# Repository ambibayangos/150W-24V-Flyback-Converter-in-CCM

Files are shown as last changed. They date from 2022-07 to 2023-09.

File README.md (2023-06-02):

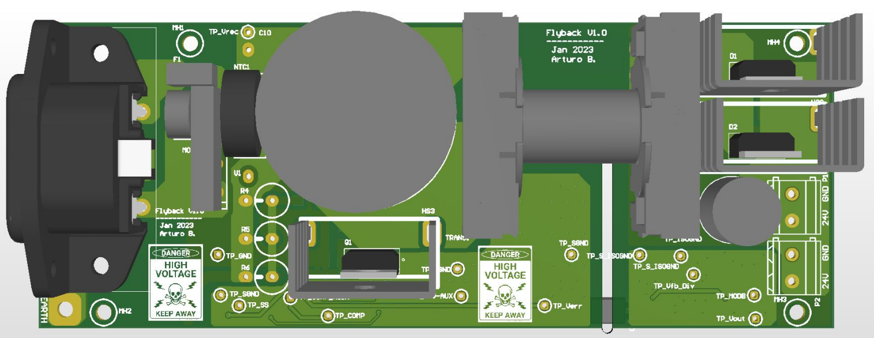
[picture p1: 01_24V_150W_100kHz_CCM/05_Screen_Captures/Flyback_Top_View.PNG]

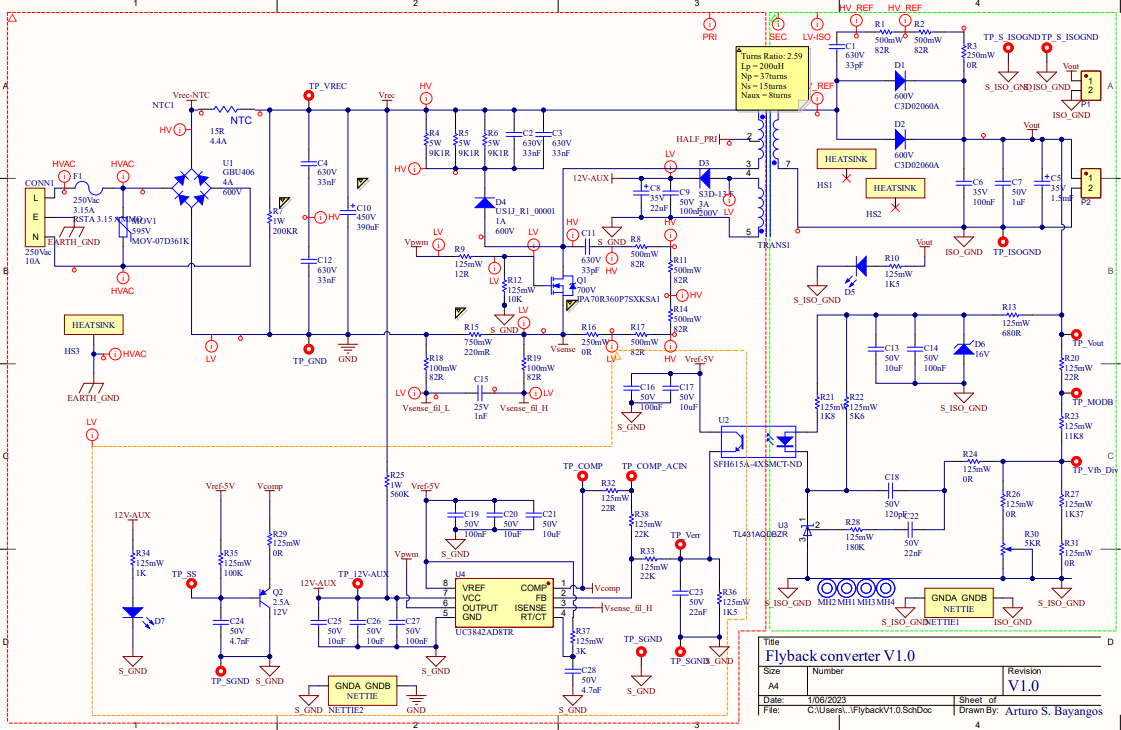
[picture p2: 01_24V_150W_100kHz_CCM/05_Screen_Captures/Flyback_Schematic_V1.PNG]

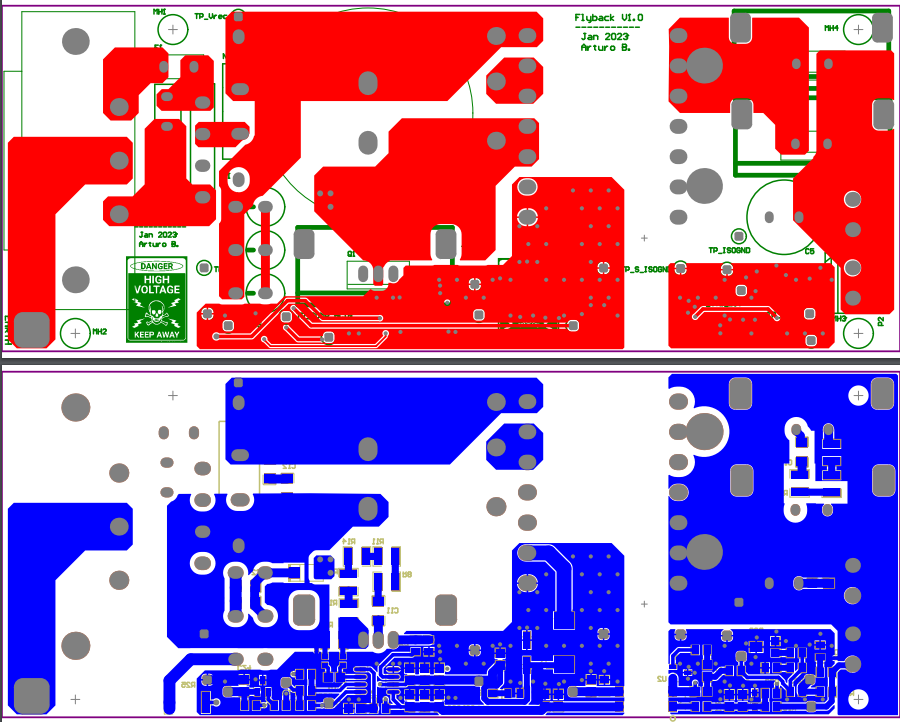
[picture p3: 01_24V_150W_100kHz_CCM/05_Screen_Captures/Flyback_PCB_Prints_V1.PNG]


# About
In this project I am designing and building a 60W,20V, dual channel digital power supply. The user will be able to set  the power supply voltage and max current using tactile buttons and an LCD display will show them their inputs as well as the PSU status.

A 150W flyback converter will convert the AC voltage from the grid to a safe DC voltage. Then, two synchronous buck converter will condition the output of the flyback converter at the user’s command which is done in the background with a microcontroller.
# Motivation
I wanted to learn how to design the feedback loop for an isolated power converter which is commonly found on flyback converter. Also, I wanted to learn how to control an LCD using a microcontroller. Finally, even though I have programmed in C before, I have always done it using ATMEL microcontroller. This time I wanted to play around with STM32 or ESP32 microcontrollers.
# Progress and What's coming
* I have designed the first protoype for the flyback converter and have the PCB file ready to be manufacture. However, I am currently too poor to buy the components to assemble it.

* I have started to design the synchronous buck converter. I have gathered enough information to pick the components for the power section. Next I need to think about how I am going to control it, and how I will implement the protection schemes.

* I need to write the code to handle the user inputs and translate them for the buck converter,  and I also need to write the logic to control the LCD display.

* Finally, I need to design an enclosure for the digital power supply.

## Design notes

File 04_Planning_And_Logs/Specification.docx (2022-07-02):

# Specification for the 150W, 12V Flyback converter in DCM

Below are the of the basic specification for this flyback converter project.

- Maximum output power: 150W
- Regulated voltage: 12V
- Switching frequency: 100kHz
- Flyback operates in DCM
- Input voltage: 230VAC
- Assumed input voltage variation: +-20%
- Assumed overall efficiency: 80%

Notes:

A quick search online indicates that in Australia, the nominal mains voltage is 230VAC (same as New Zealand) with +10% to -6% variation in accordance with the system standard AS60038.

The specification input voltage variation of 20% might be too extreme, however, since the coupled inductor could saturate at higher duty cycles which occurs at lower input voltages, the input voltage variation is decided to be exaggerated to ensure reliability for now.

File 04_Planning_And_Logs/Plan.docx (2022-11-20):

- Need to test if grounding the heatsink if the measured EMI would be reduced.
- Need to measure the open-loop response of the converter using spectrum analyser.
- Test if the simulated temperature rise in the core is same as simulation. Also Need to test if the saturation of the simulated core has same saturation current as the real core. Can also compare with analytical solution from reference books.

Verify the magnetic design with MAXWELL.

This means verify the saturation current and also verify the temperature rise is good using ICEPAK.

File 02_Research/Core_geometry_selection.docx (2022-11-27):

Pot cores

Pot cores are good for low profile applications. They naturally shield the “stray” H-field because of their enclosed geometry. However, they are not cheap.

E-cores

E cores are good for high power applications because the winding around them can be cooled more effectively due to their open construction geometry. They are apparently, easier to wind and have a lot of hardware support such as many options of bobbin and landing patterns.

Overall, this core seems to the most standardised core shape.

ETD cores or cores with round centre post (also applies for EC and EER cores)

These cores have shorter path length, which means the overall copper loss in reduced for the same number of turns. Like E-cores, they are good for high power applications since their winding can be cooled due to their wider opening construction.

Links

https://www.electronicdesign.com/technologies/passive-components/article/21192374/one-powerful-decade-keep-core-geometry-in-mind-when-designing-transformers

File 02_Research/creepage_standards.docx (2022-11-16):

Creepage distance is determined given the working RMS voltage, the pollution degree, and the material group.

The material group is defined by the CTI of the surface. The CTI can be thought of as a resistance that prevents current to flow between conductors. Thus, higher CTI means better protection against failure due to creepage.

I wonder how creepage applies to tracts inside the PCB.

It seems that pollution degree 1 can be assumed when there is no dust or moisture that can come on the PCB. Conformal coating solves this issue.

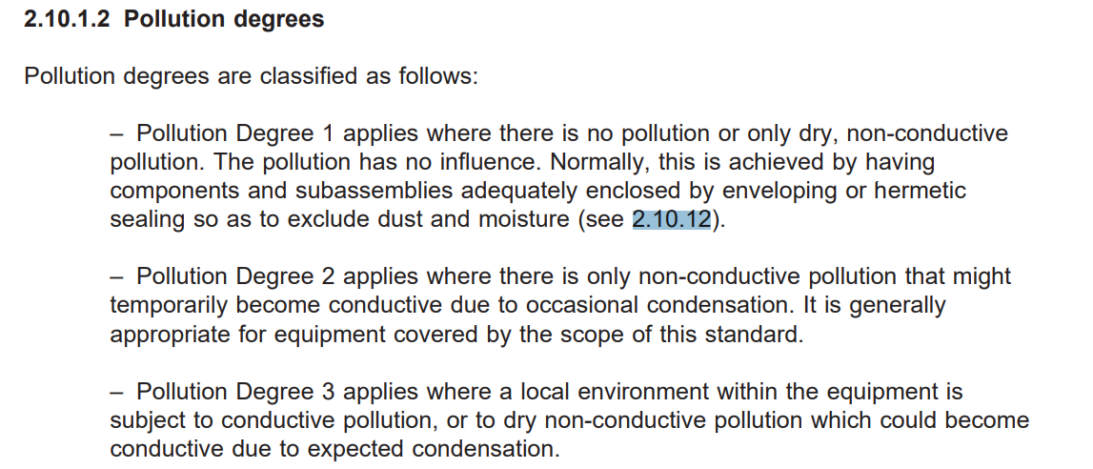
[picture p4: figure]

https://composter.com.ua/documents/IEC60950-1.pdf

https://www.techspray.com/the-essential-guide-to-conformal-coating

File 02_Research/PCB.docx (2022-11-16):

I will use critical thinking to arrive at solutions based on reasons.

A tool I can use to facilitate critical thinking is asking insightful questions. Kinda like the socratic method. In the Socratic method, one probes another’s line of thoughts by asking them questions.

But solving any problem requires initial thoughts which can be refined if needed. If I just use common sense, I should be able to arrive to solution without conducting much research but still produce a reliable product. For example, if you know the board may caught or fire then use fireproof components. Basically, the idea is to draw inspirations from experience. But of course, some things are not as obvious as you might think and require research. Things like EMI problems.

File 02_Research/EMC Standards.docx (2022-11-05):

Standards

To sell a product in a market, such product typically need to carry the certification mark required in that region. These certification mark , e.g. CE & UL, are attained by adhering the standards proposed by some testing agencies e.g. UL (underwritters Laboratories), then the product needs to be tested by the agencies in able to ensure that the product does indeed adhered to the standards they proposed.

In most countries the safety and EMC compliance mark is usually combined. But for US, the safety mark is called UL and the EMC mark if FCC.

For a tpical engineer trying to comply with EMI see “EN 550022” (Meant for IT equipment). Which is also known as CISPR22. And the American counter part is FCC part 15.

The changing magnetic and electromagnetic fields in SMPs can generate electro-magnetic fields (near field) but at some distance away they become electro-magnetic waves which can propagate into the space. This propagated wave can be picked up by other devices thus generating unwated current or voltages which can cause that particular device to malfunction. Also the radiated waves can be picked up again by the conveter it self thus contributing to it own noise.

In general as frequency increases, the electro-magnetic fields gets more intense. Thus increasing the EMI. This is because as frequency increases, the smaller trace length can be more conductive or can radiate the high frequency contents/ energy in the harmonics of the SMPs.

For EMI radiated test, the frequency can start from 30MHz-1Ghz at distances of 3m (for FCC) and 10m for (CISPR). At these distances, the EM waves will be far field.

EMC class

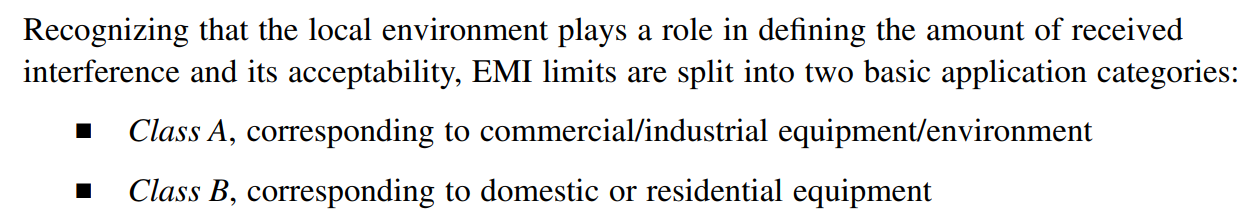
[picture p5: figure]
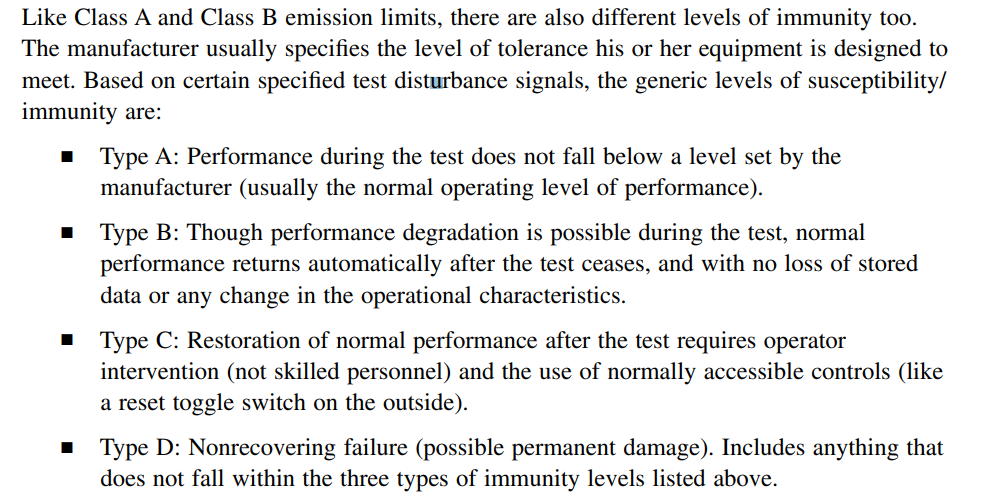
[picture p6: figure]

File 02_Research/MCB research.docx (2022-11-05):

What is MCB (Miniature Circuit Breaker)

MCBs are the circuit breakers typically found in most modern households. They are basically re-settable fuse. They can trip with two modes. First mode is slow and the trip action is due to temperature rise due to prolonged high current. The second mode is much faster which is meant to protect under short circuit conditions. The second mode has a trip reaction time of 100ms, which means that after dectecting a short, the circuit breaker can break the current within 100ms.

MCBs look like this:

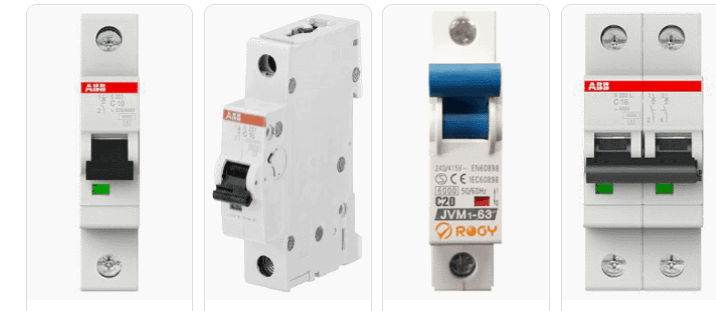
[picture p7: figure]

Types of MCB

MCBs have a rated trip current. And it addition to that, MCB also have the so called trip curves. These trip curves vary from C,B,D,A and even Z. Trip curves shows at what current the MCB will trip practically instantly. For example. For an MCB with a trip “B” trip curve, The MCB will instantly trip at 3-5 times the rated full load current, while an MCB with a “C” trip curve will instantly trip at 5-10 times of the rated full load current. Below is the trip curves (https://www.electricalclassroom.com/b-c-d-k-and-z-mcb-trip-curves/).

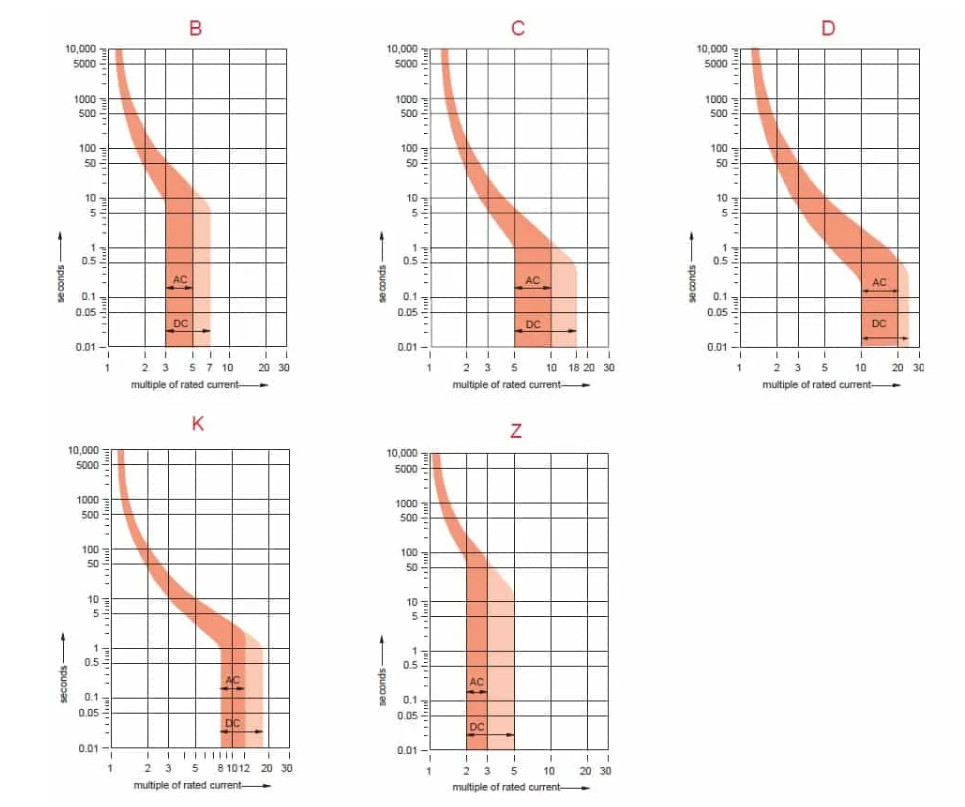
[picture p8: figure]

What type of MCB is used for home?

Seems like either MCBs that have B or C trip curves are used for home applications. See snapshot below(https://www.consumerunitworld.co.uk/what-is-an-mcb-and-how-does-it-work-328-c.asp).

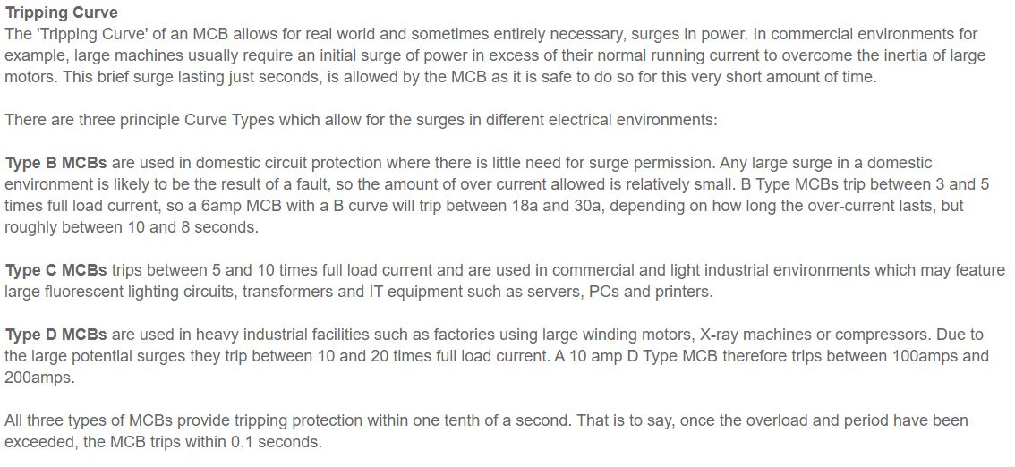
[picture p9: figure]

Further

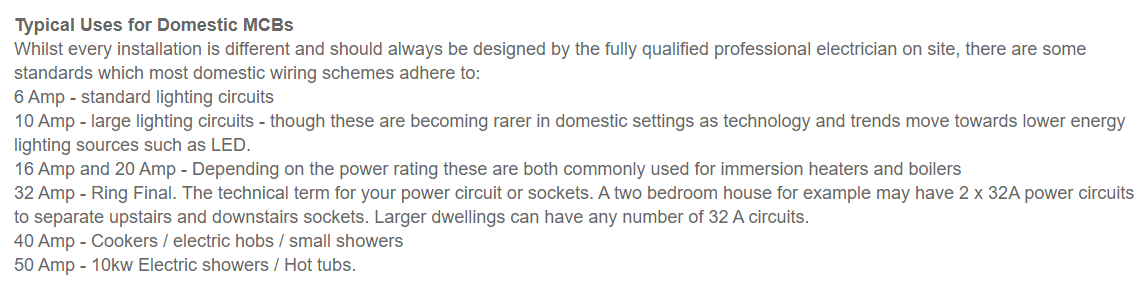
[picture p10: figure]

Conclusion

MCBs used in power sockets are likely to be 16-32A MCBs that have either “B” (3-5 x full current) or “C” (5-10 x full current).

I had a look at the MCBs of a house (@ snapperrock) it seems that the lights uses C10A , while power uses C16A or C20A. I am assuming power means the power sockets.

Ofcourse, the power sockets have other circuits connected to it that why the trip current is probably higher. But there is no way of knowing what circuits are connected to what loop.

Links

https://www.electricalclassroom.com/b-c-d-k-and-z-mcb-trip-curves/

https://www.consumerunitworld.co.uk/what-is-an-mcb-and-how-does-it-work-328-c.asp

https://uk.rs-online.com/web/generalDisplay.html?id=ideas-and-advice/mcb-guide

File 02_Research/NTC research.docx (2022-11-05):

Dissipation factor and what it means

Dissipation factor gives the rate of heat generated per second (i.e Ploss) for a given temperature rise above the ambient temperature. Therefore, it has a unit of W/K.

Power limitation of the device

It seems that the power limitation of the device, Pmax, gives the amount of power dissipation before the NTC goes into thermal runaway. Thus, I think Pmax is the power where the amount of energy generated within the NTC is equal to the amount of energy the NTC can remove from its body

Ctest

In for NTC used for inrush current limiting, the inrush current can be associated with a pulse of energy during the impulse. This energy needs to know in able to select an appropriate NTC size. Manufacturers typically, associate this energy with a capacitor discharge for a given voltage thus giving a capacitance for a given voltage and energy.

General steps to pick

1.)Pick the size – Size can be determined by the Ctest. Basically, if the pulse energy is known , then a corresponding Ctest can be matched for a given line voltage.

2.) Choose the R25 to limit the inrush current.

3.) Make sure the maximum steady state current if higher enough.

Links

https://www.newark.com/wcsstore/ExtendedSitesCatalogAssetStore/cms/asset/images/americas/common/storefront/epcos/inrushCurrentLimiters.pdf

https://www.tdk-electronics.tdk.com/download/2982800/f5be4fca9d1f66204de9cf37891e5265/ntc-thermistors-icl-an.pdf

https://www.tdk-electronics.tdk.com/download/531338/d80caa7d75198765c2534bc19da9b73d/pdf-general-technical-information.pdf

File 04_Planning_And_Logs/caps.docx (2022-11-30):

D = 0.18 , Vout = 16ishV

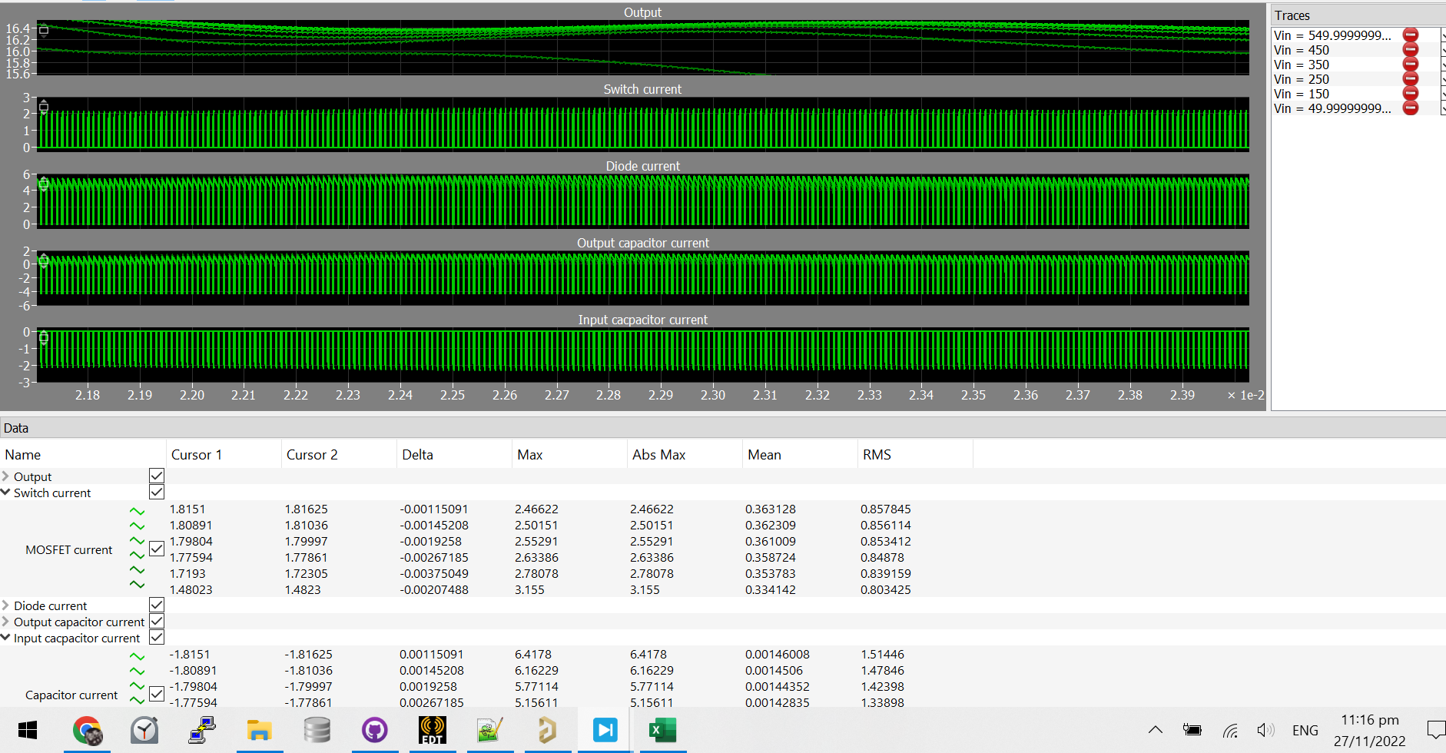
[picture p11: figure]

D = 0.25 , Vo = 25ish

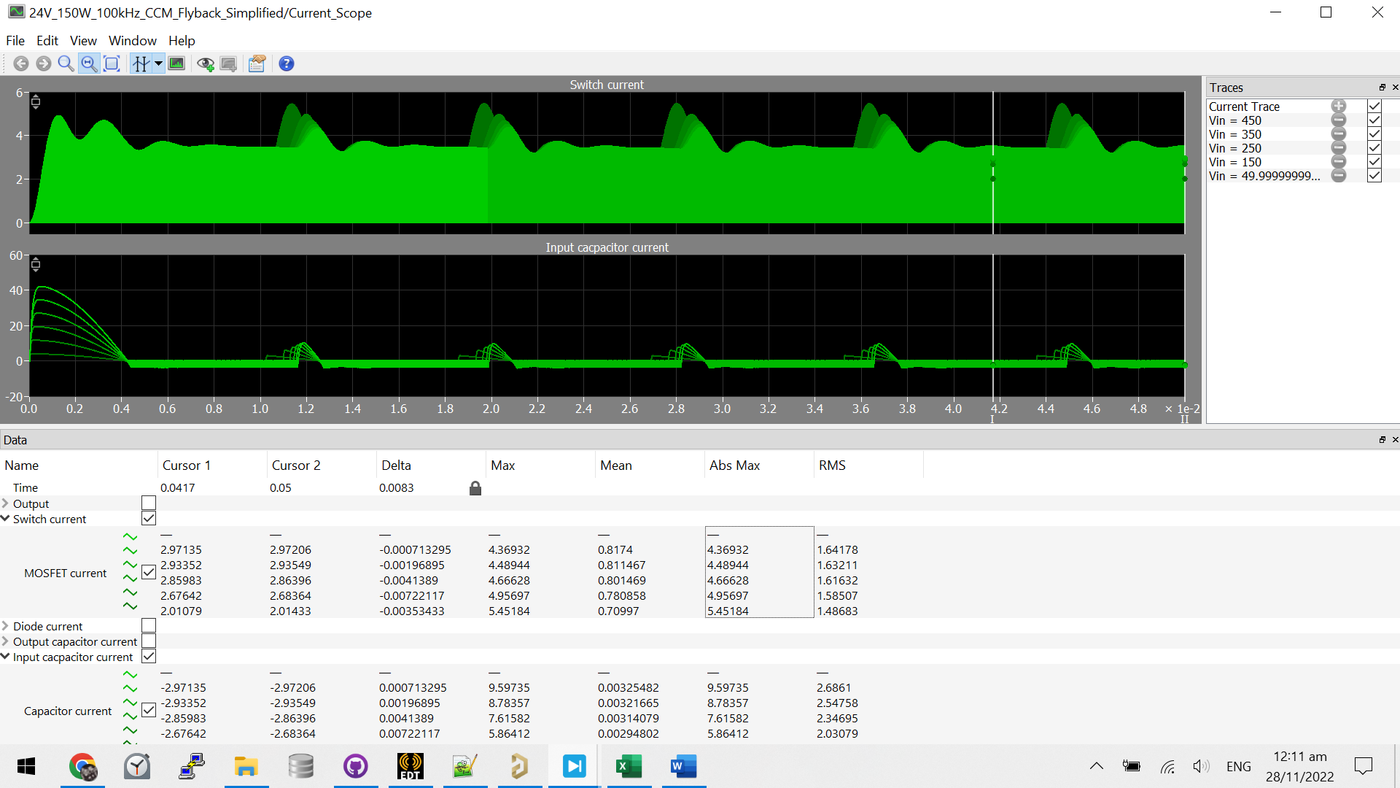
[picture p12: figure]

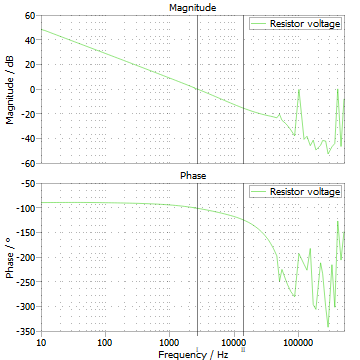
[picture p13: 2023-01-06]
01_24V_150W_100kHz_CCM/05_Screen_Captures/CCM_24V_150W_Open_Loop_Lp200uH_Compensated.png

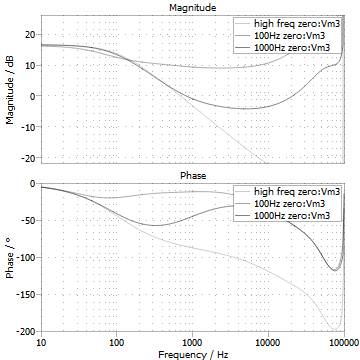
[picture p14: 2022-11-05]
01_24V_150W_100kHz_CCM/05_Screen_Captures/CCM_24V_150W_Open_Loop_Response.png

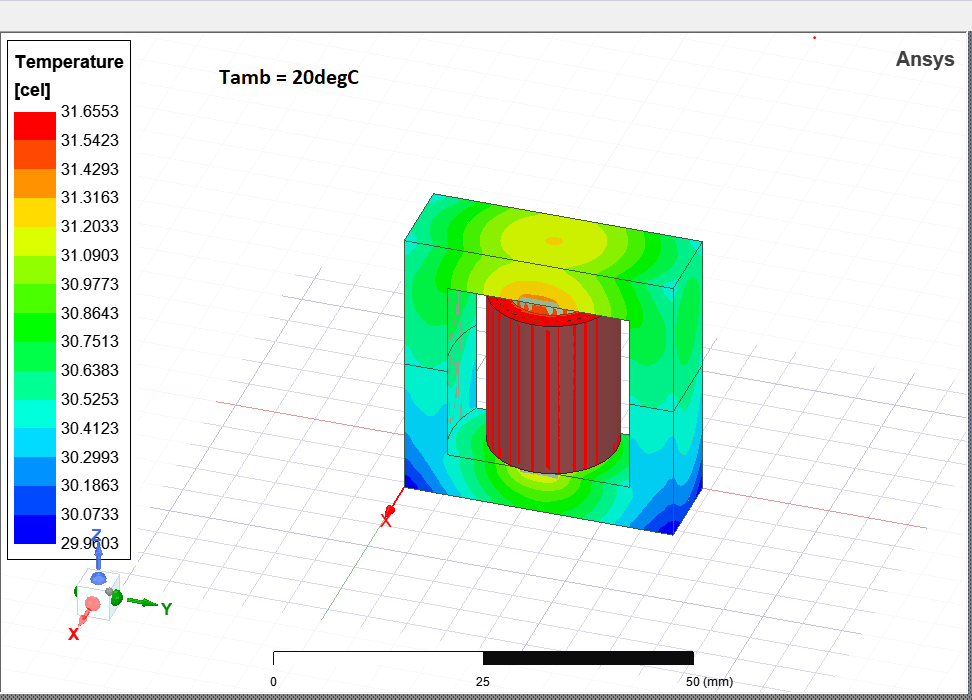
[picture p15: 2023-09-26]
01_24V_150W_100kHz_CCM/05_Screen_Captures/ETD34_1mm_20degCAmb.png

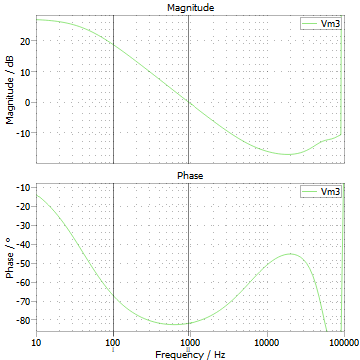
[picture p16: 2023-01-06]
01_24V_150W_100kHz_CCM/05_Screen_Captures/CCM_24V_150W_Open_Loop_Lp200uH.png

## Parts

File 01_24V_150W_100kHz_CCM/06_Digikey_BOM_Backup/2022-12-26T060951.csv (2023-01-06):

Index | Quantity | Part Number | Manufacturer Part Number | Description | Customer Reference | Available | Backorder | Unit Price | Extended Price NZD
1 | 2 | 565-4474-ND | ESMR401VSN391MA25S | CAP ALUM 390UF 20% 400V SNAP | Cin - 2.05A @ 120Hz , 400V | 2 | 0 | 12.47000 | 24.94
2 | 4 | 495-3058-ND | B57238S0150M000 | ICL 15 OHM 20% 4.4A 16MM | NTC 16MM 700UF , 15OHM | 4 | 0 | 2.32000 | 9.28
3 | 1 | 3M10226-ND | 3/4-5-1205 | TAPE FILM AMBER 3/4"X 5YDS | INSULATION TAPE | 1 | 0 | 41.21000 | 41.21
4 | 4 | IPA70R360P7SXKSA1-ND | IPA70R360P7SXKSA1 | MOSFET N-CH 700V 12.5A TO220 | MAIN MOSFET | 4 | 0 | 3.40000 | 13.60
5 | 2 | 732-9228-1-ND | 860040578017 | CAP ALUM 1500UF 20% 35V RADIAL | Cout - 35V , 3A @100kHz, 1.5mF | 2 | 0 | 4.25000 | 8.50
6 | 6 | A142823CT-ND | ROX5SSJ9K1 | RES 9.1K OHM 5% 5W AXIAL | RCD resistor - 9.1k,5W,750V (need 3 in parallel) | 6 | 0 | 1.13000 | 6.78
7 | 4 | 31-FUS1JE-7CT-ND | FUS1JE-7 | DIODE GEN PURP 600V 1A F1A | RCD diode - 600V , 1.7V , Trr = 75ns | 4 | 0 | 0.64000 | 2.56
8 | 2 | 1801-GBU406-ND | GBU406 | BRIDGE RECT 1PHASE 800V 4A GBU | Bridge rectifier | 2 | 0 | 2.22000 | 4.44
9 | 4 | C3D02060A-ND | C3D02060A | DIODE SIL CARB 600V 5A TO220-2 | Output diode - 600V , Vf = 1.7V , SiC , T0-220 | 4 | 0 | 2.82000 | 11.28
10 | 4 | AE10898-ND | V5630-T | HEATSINK ALUM ANOD | MOSFET and DIODE HEATSINK - 15.00°C/W | 4 | 0 | 0.82000 | 3.28
11 | 2 | 1189-3666-ND | 35ZLQ1500MEFC12.5X30 | CAP ALUM 1500UF 20% 35V RADIAL | Output cap , 1.5mF , 35V , Irms = 3.68A @ 100khz | 2 | 0 | 2.90000 | 5.80
12 | 6 | 507-1870-1-ND | RSTA 3.15 AMMO | FUSE BRD MNT 3.15A 250VAC/63VDC | Input fuse | 6 | 0 | 0.64600 | 3.88
13 | 4 | MOV-07D361K-ND | MOV-07D361K | VARISTOR 360V 1.2KA DISC 7MM | MOV - 595V @ 10A for 20-30us | 4 | 0 | 0.61000 | 2.44
14 | 4 | VR68J200KCT-ND | VR68000002003JAC00 | RES 200K OHM 1W 5% AXIAL | Bleed resistor- 200kR , 1W , 10kV | 4 | 0 | 1.38000 | 5.52
15 | 3 | 495-5464-ND | B66362B1014T001 | BOBBIN COIL FORMER ETD 34X17X11 | ETD34 - Bobbin Horizontal | 3 | 0 | 4.11000 | 12.33
16 | 8 | 495-5463-ND | B66362A2000X000 | YOKE ETD 34 X 17 X 11 | ETD34 Yoke | 8 | 0 | 0.97000 | 7.76
17 | 2 | 495-5462-ND | B66361G0000X187 | FERRITE CORE ETD N87 1PC | ETD34 - Not Gapped | 2 | 0 | 2.77000 | 5.54
18 | 2 | 495-5457-ND | B66361G1000X187 | FERRITE CORE ETD N87 1PC | ETD34 - 1mm gap | 2 | 0 | 3.77000 | 7.54
19 | 4 | SFH615A-4XSMCT-ND | SFH615A-4XSMT/R | OPTOISOLATOR 5.3KV TRANS 4SMD | optocoupler SMD | 4 | 0 | 0.91000 | 3.64

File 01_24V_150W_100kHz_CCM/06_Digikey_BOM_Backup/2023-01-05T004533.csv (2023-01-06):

Index | Quantity | Part Number | Manufacturer Part Number | Description | Customer Reference | Available | Backorder | Unit Price | Extended Price NZD
1 | 2 | 565-4474-ND | ESMR401VSN391MA25S | CAP ALUM 390UF 20% 400V SNAP | Cin - 2.05A @ 120Hz , 400V | 2 | 0 | 11.81000 | 23.62
2 | 4 | 495-3058-ND | B57238S0150M000 | ICL 15 OHM 20% 4.4A 16MM | NTC 16MM 700UF , 15OHM | 4 | 0 | 2.20000 | 8.80
3 | 1 | 3M10226-ND | 3/4-5-1205 | TAPE FILM AMBER 3/4"X 5YDS | INSULATION TAPE | 1 | 0 | 43.32000 | 43.32
4 | 4 | IPA70R360P7SXKSA1-ND | IPA70R360P7SXKSA1 | MOSFET N-CH 700V 12.5A TO220 | MAIN MOSFET | 4 | 0 | 3.07000 | 12.28
5 | 2 | 732-9228-1-ND | 860040578017 | CAP ALUM 1500UF 20% 35V RADIAL | Cout - 35V , 3A @100kHz, 1.5mF | 2 | 0 | 4.02000 | 8.04
6 | 6 | A142823CT-ND | ROX5SSJ9K1 | RES 9.1K OHM 5% 5W AXIAL | RCD resistor - 9.1k,5W,750V (need 3 in parallel) | 6 | 0 | 1.13000 | 6.78
7 | 4 | 31-FUS1JE-7CT-ND | FUS1JE-7 | DIODE GEN PURP 600V 1A F1A | RCD diode - 600V , 1.7V , Trr = 75ns | 4 | 0 | 0.63000 | 2.52
8 | 2 | 1801-GBU406-ND | GBU406 | BRIDGE RECT 1PHASE 800V 4A GBU | Bridge rectifier | 2 | 0 | 2.22000 | 4.44
9 | 4 | C3D02060A-ND | C3D02060A | DIODE SIL CARB 600V 5A TO220-2 | Output diode - 600V , Vf = 1.7V , SiC , T0-220 | 4 | 0 | 2.82000 | 11.28
10 | 4 | AE10898-ND | V5630-T | HEATSINK ALUM ANOD | MOSFET and DIODE HEATSINK - 15.00°C/W | 4 | 0 | 0.82000 | 3.28
11 | 2 | 1189-3666-ND | 35ZLQ1500MEFC12.5X30 | CAP ALUM 1500UF 20% 35V RADIAL | Output cap , 1.5mF , 35V , Irms = 3.68A @ 100khz | 2 | 0 | 2.90000 | 5.80
12 | 6 | 507-1870-1-ND | RSTA 3.15 AMMO | FUSE BRD MNT 3.15A 250VAC/63VDC | Input fuse | 6 | 0 | 0.64600 | 3.88
13 | 4 | MOV-07D361K-ND | MOV-07D361K | VARISTOR 360V 1.2KA DISC 7MM | MOV - 595V @ 10A for 20-30us | 4 | 0 | 0.61000 | 2.44
14 | 4 | VR68J200KCT-ND | VR68000002003JAC00 | RES 200K OHM 1W 5% AXIAL | Bleed resistor- 200kR , 1W , 10kV | 4 | 0 | 1.38000 | 5.52
15 | 3 | 495-5464-ND | B66362B1014T001 | BOBBIN COIL FORMER ETD 34X17X11 | ETD34 - Bobbin Horizontal | 3 | 0 | 4.11000 | 12.33
16 | 8 | 495-5463-ND | B66362A2000X000 | YOKE ETD 34 X 17 X 11 | ETD34 Yoke | 8 | 0 | 0.97000 | 7.76
17 | 4 | 495-5462-ND | B66361G0000X187 | FERRITE CORE ETD N87 1PC | ETD34 - Not Gapped | 4 | 0 | 2.77000 | 11.08
18 | 4 | 495-5457-ND | B66361G1000X187 | FERRITE CORE ETD N87 1PC | ETD34 - 1mm gap | 4 | 0 | 3.77000 | 15.08
19 | 4 | SFH615A-4XSMCT-ND | SFH615A-4XSMT/R | OPTOISOLATOR 5.3KV TRANS 4SMD | optocoupler SMD | 4 | 0 | 0.91000 | 3.64
20 | 10 | 36-5271-ND | 5271 | TEST POINT (BLACK) - COMPACT | Black TP | 10 | 0 | 0.56800 | 5.68
21 | 10 | 36-5270-ND | 5270 | TEST POINT (RED) - COMPACT | REDTP | 10 | 0 | 0.56800 | 5.68
22 | 6 | 102-4185-ND | HSS-B20-NPS-02 | HEATSINK TO-220 5.1W ALUMINUM | TO-220 HS - RHC = 14.71°C/W | 6 | 0 | 1.02000 | 6.12
23 | 16 | 36-25505-ND | 25505 | HEX STANDOFF M3 NYLON 20MM | M3 - 20mm standoff | 16 | 0 | 1.11000 | 17.76
24 | 15 | 36-5001-ND | 5001 | PC TEST POINT MINIATURE BLACK | MINI TP BLACK | 15 | 0 | 0.75000 | 11.25
25 | 15 | 36-5000-ND | 5000 | PC TEST POINT MINIATURE RED | MINI TP RED | 15 | 0 | 0.75000 | 11.25

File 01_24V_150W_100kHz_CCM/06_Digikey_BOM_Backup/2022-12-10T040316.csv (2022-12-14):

Index | Quantity | Part Number | Manufacturer Part Number | Description | Customer Reference | Available | Backorder | Unit Price | Extended Price NZD
1 | 2 | 565-4474-ND | ESMR401VSN391MA25S | CAP ALUM 390UF 20% 400V SNAP | Cin - 2.05A @ 120Hz , 400V | 2 | 0 | 12.47000 | 24.94
2 | 1 | 532702B02500G-ND | 532702B02500G | HEATSINK TO-220 SOLDERPIN 50.8MM | T220 HEATSINK | 1 | 0 | 11.68000 | 11.68
3 | 2 | 495-5481-ND | B66366B1018T001 | BOBBIN COIL FORMER ETD 44X22X15 | ETD44 BOBBIN | 2 | 0 | 5.23000 | 10.46
4 | 4 | 497-7577-5-ND | STTH1202D | DIODE GEN PURP 200V 12A TO220AC | MAIN DIODE | 0 | 4 | 4.83000 | 19.32
5 | 2 | 495-5474-ND | B66365G1000X187 | FERRITE CORE ETD N87 1PC | ETD44 1MM AIR GAP | 2 | 0 | 8.38000 | 16.76
6 | 6 | 493-1618-ND | UHE1H681MHD | CAP ALUM 680UF 20% 50V RADIAL | OUTPUT CAPACITORS | 4 | 2 | 2.62000 | 15.72
7 | 4 | 495-3058-ND | B57238S0150M000 | ICL 15 OHM 20% 4.4A 16MM | NTC 16MM 700UF , 15OHM | 4 | 0 | 2.32000 | 9.28
8 | 2 | 493-2618-ND | LLS2W391MELC | CAP ALUM 390UF 20% 450V SNAP | INPUT CAPS | 2 | 0 | 16.00000 | 32.00
9 | 6 | 495-5480-ND | B66366A2000X000 | YOKE ETD 44 X 22 X 15 | ETD44 CLIP | 6 | 0 | 1.49000 | 8.94
10 | 1 | 3M10226-ND | 3/4-5-1205 | TAPE FILM AMBER 3/4"X 5YDS | INSULATION TAPE | 1 | 0 | 41.21000 | 41.21
11 | 4 | IPA70R360P7SXKSA1-ND | IPA70R360P7SXKSA1 | MOSFET N-CH 700V 12.5A TO220 | MAIN MOSFET | 4 | 0 | 3.40000 | 13.60
12 | 1 | 3M156589-ND | 0.125-5-4910 | TAPE DBL COATED CLEAR 1/8"X 5YDS | 3MM MARGIN TAPE | 1 | 0 | 20.34000 | 20.34
13 | 2 | 732-9228-1-ND | 860040578017 | CAP ALUM 1500UF 20% 35V RADIAL | Cout - 35V , 3A @100kHz, 1.5mF | 2 | 0 | 4.25000 | 8.50
14 | 4 | 493-2572-ND | LLS2G151MELZ | CAP ALUM 150UF 20% 400V SNAP | Input caps - 150uF , 400V, 1.24@120Hz (need 2min | 4 | 0 | 6.79000 | 27.16
15 | 6 | A142823CT-ND | ROX5SSJ9K1 | RES 9.1K OHM 5% 5W AXIAL | RCD resistor - 9.1k,5W,750V (need 3 in parallel) | 6 | 0 | 1.13000 | 6.78
16 | 4 | 31-FUS1JE-7CT-ND | FUS1JE-7 | DIODE GEN PURP 600V 1A F1A | RCD diode - 600V , 1.7V , Trr = 75ns | 4 | 0 | 0.64000 | 2.56
17 | 2 | GBU406DI-ND | GBU406 | BRIDGE RECT 1PHASE 600V 4A GBU | Bridge rectifier | 2 | 0 | 2.54000 | 5.08
18 | 2 | 1801-GBU406-ND | GBU406 | BRIDGE RECT 1PHASE 800V 4A GBU | Bridge rectifier | 2 | 0 | 2.22000 | 4.44

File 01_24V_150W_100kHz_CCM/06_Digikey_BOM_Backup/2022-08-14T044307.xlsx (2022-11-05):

Index | Quantity | Part Number | Manufacturer Part Number | Description | Customer Reference | Available | Backorder | Unit Price | Extended Price NZD
1 | 2 | 495-5474-ND | B66365G1000X187 | FERRITE CORE ETD N87 1PC | ETD44 1mm air gap | 2 | 0 | 8.19 | 16.38
2 | 2 | 495-5481-ND | B66366B1018T001 | BOBBIN COIL FORMER ETD 44X22X15 | ETD44 bobbin | 2 | 0 | 5.11 | 10.22
3 | 6 | 495-5480-ND | B66366A2000X000 | YOKE ETD 44 X 22 X 15 | ETD44 clip | 6 | 0 | 1.47 | 8.82
4 | 1 | 3M10226-ND | 3/4-5-1205 | TAPE FILM AMBER 3/4"X 5YDS | Insulation tape | 1 | 0 | 38.79 | 38.79
5 | 4 | IPA70R360P7SXKSA1-ND | IPA70R360P7SXKSA1 | MOSFET N-CH 700V 12.5A TO220 | Main Mosfet | 4 | 0 | 3.2 | 12.80
6 | 1 | 532702B02500G-ND | 532702B02500G | HEATSINK TO-220 SOLDERPIN 50.8MM | T220 Heatsink | 1 | 0 | 9.47 | 9.47
7 | 4 | 497-7577-5-ND | STTH1202D | DIODE GEN PURP 200V 12A TO220AC | Main Diode | 4 | 0 | 4.55 | 18.20
8 | 1 | 3M156589-ND | 0.125-5-4910 | TAPE DBL COATED CLEAR 1/8"X 5YDS | 3mm margin tape | 1 | 0 | 19.15 | 19.15
9 | 2 | 493-2618-ND | LLS2W391MELC | CAP ALUM 390UF 20% 450V SNAP | Input caps | 2 | 0 | 14.4 | 28.80
10 | 6 | 493-1618-ND | UHE1H681MHD | CAP ALUM 680UF 20% 50V RADIAL | Output capacitors | 6 | 0 | 2.47 | 14.82
11 | 20 | 36-5014-ND | 5014 | PC TEST POINT MULTI PURP YELLOW | Test point | 20 | 0 | 0.75 | 15.00
12 | 4 | 495-3058-ND | B57238S0150M000 | ICL 15 OHM 20% 4.4A 16MM | NTC 16mm 700uF , 15ohm | 4 | 0 | 2.18 | 8.72

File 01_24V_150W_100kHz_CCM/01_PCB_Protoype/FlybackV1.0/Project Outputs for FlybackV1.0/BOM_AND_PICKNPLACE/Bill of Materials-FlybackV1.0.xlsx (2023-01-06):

Comment | Description | Designator | Part_Number | JLC# | Footprint | Quantity | LibRef
CAP_33P_1206_630V_COG_5% | 630V 33pF C0G ±5% 1206 Multilayer Ceramic Capacitors MLCC - SMD/SMT ROHS | C1, C11 | GRM31A5C2J330JW01D | C415521 | CAP_1206 | 2 | CAP_33P_1206_630V_COG_5%
CAP_33N_1206_630V_X7R_10% | Ceramic cap 33nF, 630V , X7R , 1206 , 10% | C2, C3, C4, C12 | NM1206B333K631CEGN | C710477 | CAP_1206 | 4 | CAP_33N_1206_630V_X7R_10%
CAP_1M5_35V_20%_TH-Radial-P5mm-D12.5mm-H16mm | 1500 µF 35 V Aluminum Electrolytic Capacitors Radial, Can 6000 Hrs @ 105°C | C5 | 35ZLQ1500MEFC12.5X30 | ? | CAP_TH_Radial_P5mm_D12.5mm_H16mm | 1 | CAP_1M5_35V_20%_TH-Radial-P5mm-D12.5mm-H16mm
CAP_100N_1206_35V_X7R_10% | 50V 100nF X7R ±10% 1206 Multilayer Ceramic Capacitors MLCC - SMD/SMT ROHS | C6 | CL31B104KBCNNNC | C24497 | CAP_1206 | 1 | CAP_100N_1206_35V_X7R_10%
CAP_1U_0805_50V_X7R_10% | 50V 1uF X7R ±10% 0805 Multilayer Ceramic Capacitors MLCC - SMD/SMT ROHS | C7 | CL21B105KBFNNNE | C28323 | CAP_0805 | 1 | CAP_1U_0805_50V_X7R_10%
CAP_22U_35V_20%_SMD-D5mm-L5.3mm | -45℃~+105℃ 1000hrs@105℃ 22uF 5.3mm 35V 5mm ±20% SMD,D5xL5.3mm Aluminum Electrolytic Capacitors - SMD ROHS | C8 | VES220M1VTR-0505 | C249702 | CAP_SMD_D5mm-L5.3mm | 1 | CAP_22U_35V_20%_SMD-D5mm-L5.3mm
CAP_100N_0805_50V_X7R_10% | 50V 100nF X7R ±10% 0805 Multilayer Ceramic Capacitors MLCC - SMD/SMT ROHS | C9, C14, C16, C19, C27 | CC0805KRX7R9BB104 | C49678 | CAP_0805 | 5 | CAP_100N_0805_50V_X7R_10%
CAP_390U_450V_20%_TH-Radial-P10mm-D35mm-H27.5mm | Polarized Capacitor (Radial) 390UF, 450V, 20%, 2.05A @ 120Hz TH Radial 10m Pitch , 35mm Diameter , 27.5mm Heigth | C10 | ESMR401VSN391MA25S | ? | CAP_TH_Radial_P10mm_D35mm_H27.5mm | 1 | CAP_390U_450V_20%_TH-Radial-P10mm-D35mm-H27.5mm
CAP_10U_0805_50V_X5R_10% | 50V 10uF X5R ±10% 0805 Multilayer Ceramic Capacitors MLCC - SMD/SMT ROHS | C13, C17, C20, C21, C25, C26 | GRM21BR61H106KE43L | C440198 | CAP_0805 | 6 | CAP_10U_0805_50V_X5R_10%
CAP_1N_0805_25V_X7R_10% | 25V 1nF X7R ±10% 0805 Multilayer Ceramic Capacitors MLCC - SMD/SMT ROHS | C15 | CC0805KRX7R8BB102 | C519910 | CAP_0805 | 1 | CAP_1N_0805_25V_X7R_10%
CAP_120P_0805_50V_X7R_10% | 50V 120pF X7R ±10% 0805 Multilayer Ceramic Capacitors MLCC - SMD/SMT ROHS | C18 | TCC0805X7R121K500BT | C376930 | CAP_0805 | 1 | CAP_120P_0805_50V_X7R_10%
CAP_22N_0805_50V_X7R_10% | 50V 22nF X7R ±10% 0805 Multilayer Ceramic Capacitors MLCC - SMD/SMT ROHS | C22, C23 | CL21B223KBANNNC | C1729 | CAP_0805 | 2 | CAP_22N_0805_50V_X7R_10%
CAP_4N7_0805_50V_X7R_10% | 50V 4.7nF X7R ±10% 0805 Multilayer Ceramic Capacitors MLCC - SMD/SMT ROHS | C24, C28 | 0805B472K500NT | C1744 | CAP_0805 | 2 | CAP_4N7_0805_50V_X7R_10%
AC_CONNECTOR | Power Entry Connector Receptacle, Male Blades IEC 320-C14 Panel Mount, Flange; Through Hole, Right Angle | CONN1 | 703W-00/54 |  | AC_CONNECTOR_703W-00/54 | 1 | AC_CONNECTOR
DIODE_600V_3KPW8_SIC_T0220 | Diode Silicon Carbide Schottky 600 V 5A Through Hole TO-220-2 | D1, D2 | C3D02060A | ? | T0-220-2 | 2 | DIODE_600V_3KPW8_SIC_T0220
DIODE_200V_3A_20ns_SMC | 3A 10uA@200V 200V 1.15V@3A SMC(DO-214AB) Diodes - General Purpose ROHS | D3 | S3D-13-F | C156341 | DIODE_SMC | 1 | DIODE_200V_3A_20ns_SMC
DIODE_600V_1A_100ns_SMA | 1.7V@1A 1uA@600V 100ns Single 1A -55℃~+150℃@(Tj) 600V SMA Diodes - Fast Recovery Rectifiers ROHS | D4 | US1J_R1_00001 | C391757 | SMA_L4.4-W2.6-LS5.0-RD | 1 | DIODE_600V_1A_100ns_SMA
LED_GREEN_0805_25mA | Green/Yellow-Green 0805 Light Emitting Diodes (LED) ROHS | D5, D7 | 17-215/GPC-AL1M2L/3T | C264433 | LED_0805 | 2 | LED_GREEN_0805_25mA
ZENER_16V_SOD323_200mW | 0.1uA@11.2V 40Ω 15.3V~17.1V 200mW 16V SOD-323 Zener Diodes ROHS | D6 | BZT52C16SQ-7-F | C691210 | ZENER_SOD-323 | 1 | ZENER_16V_SOD323_200mW
FUSE_3.15A_250VAC_64VDC_SlowBlow_BoardMount | 3.15 A 250 V AC 63 V DC Fuse Board Mount (Cartridge Style Excluded) Through Hole Radial, Box | F1 | RSTA 3.15 AMMO |  | FUSE_P5.08mm_W4mm_L8.35mm_H7.8mm | 1 | FUSE_3.15A_250VAC_64VDC_SlowBlow_BoardMount
HEATSINK_TO-220_14.7KPW | Heat Sink TO-220 Aluminum 5.1W @ 75°C Board Level | HS1, HS2, HS3 | HSS-B20-NPS-02 |  | HEATSINK_TO-220_HSS-B20-NPS-02 | 3 | HEATSINK_TO-220_14.7KPW
MOUNTINGHOLE_HDM3_OD3mm |  | MH1, MH2, MH3, MH4 |  |  | STANDOFF_HDM3_OD5mm | 4 | MOUNTINGHOLE_HDM3_OD3mm
MOV_VC595_VAC230 | 360 V 1.2 kA Varistor 1 Circuit Through Hole Disc 7mm | MOV1 | MOV-07D361K |  | MOV_P5mm_D9mm_W4.4mm | 1 | MOV_VC595_VAC230
NETTIE | NETTIE | NETTIE1, NETTIE2 |  |  | NETTIE | 2 | NETTIE
NTC_15R_4.4A_D16mm | Inrush Current Limiter 15 Ohms ±20% 4.4 A 0.630" (16.00mm) | NTC1 | B57238S0150M000 | ? | NTC_P7.5mm_D16mm | 1 | NTC_15R_4.4A_D16mm
SCREWTERMINAL_P5.08mm | Copper 0.2~2 -40℃~+105℃ 15A 300V Green Tin 250℃ 5.08mm 1 26~14 2 P=5.08mm Screw terminal ROHS | P1, P2 | JL500-50802G01 | C709041 | SCREW_TERMINAL_P5.08mm | 2 | SCREWTERMINAL_P5.08mm
NMOS_700V_IPA70R360P7SXKSA1 | N-Channel Power MOSFET, 700Vds, T0-220-3 | Q1 | IPA70R360P7SXKSA1 | ? | T0-220-3 | 1 | NMOS_700V_IPA70R360P7SXKSA1
PNP_12V_2.5A_SOT-23-3 | 12V 625mW 2.5A PNP SOT-23-3 Bipolar Transistors - BJT ROHS | Q2 | FMMT717TA | C500779 | SOT-23-3 | 1 | PNP_12V_2.5A_SOT-23-3
RES_82R_1210_0.5W_1% | 500mW Thick Film Resistors 200V ±100ppm/℃ ±5% -55℃~+155℃ 82Ω 1210 Chip Resistor - Surface Mount ROHS | R1, R2, R8, R11, R14, R17 | RC1210JR-0782RL | C728413 | RES_1210 | 6 | RES_82R_1210_0.5W_1%
RES_0R_1206_0.25W_1% | 250mW Thick Film Resistors 200V ±800ppm/℃ ±1% -55℃~+155℃ 0Ω 1206 Chip Resistor - Surface Mount ROHS | R3, R16 | 1206W4F0000T5E | C17888 | RES_1210 | 2 | RES_0R_1206_0.25W_1%
RES_9K1_TH_5W_5%_AXIAL | 9.1 kOhms ±5% 5W Through Hole Resistor Axial Flame Proof, Pulse Withstanding, Safety Metal Oxide Film | R4, R5, R6 | ROX5SSJ9K1 | ? | RES_TH_AXIAL_L17.5mm_D6.5mm_Vertical | 3 | RES_9K1_TH_5W_5%_AXIAL
RES_200K_TH_1W_5%_AXIAL | 200 kOhms ±5% 1W Through Hole Resistor Axial High Voltage, Pulse Withstanding Metal Film | R7 | VR68000002003JAC00 | ? | RES_TH_AXIAL_L18mm_D6.8mm | 1 | RES_200K_TH_1W_5%_AXIAL
RES_12R_0805_0.125W_5% | 125mW Thick Film Resistors 150V ±1% ±200ppm/℃ -55℃~+155℃ 12Ω 0805 Chip Resistor - Surface Mount ROHS | R9 | 0805W8F120JT5E | C17445 | RES_0805 | 1 | RES_12R_0805_0.125W_5%
RES_1K5_0805_0.125W_1% | 125mW Thick Film Resistors 150V ±100ppm/℃ ±1% -55℃~+155℃ 1.5kΩ 0805 Chip Resistor - Surface Mount ROHS | R10, R36 | 0805W8F1501T5E | C4310 | RES_0805 | 2 | RES_1K5_0805_0.125W_1%
RES_10K_0805_0.125W_1% | 125mW Thick Film Resistors 150V ±100ppm/℃ ±1% -55℃~+155℃ 10kΩ 0805 Chip Resistor - Surface Mount ROHS | R12 | 0805W8F1002T5E | C17414 | RES_0805 | 1 | RES_10K_0805_0.125W_1%
RES_680R_0805_0.125W_1% | 125mW Thick Film Resistors 150V ±100ppm/℃ ±1% -55℃~+155℃ 680Ω 0805 Chip Resistor - Surface Mount ROHS | R13 | 0805W8F6800T5E | C17798 | RES_0805 | 1 | RES_680R_0805_0.125W_1%
RES_220mR_1210_0.75W_1% | 1W Thick Film Resistors 800V ±1% -55℃~+155℃ 560kΩ 2512 Chip Resistor - Surface Mount ROHS | R15 | RTT20R220FTE | C159209 | RES_1210 | 1 | RES_220mR_1210_0.75W_1%
RES_82R_0603_0.1W_1% | 100mW Thick Film Resistors 75V ±100ppm/℃ ±1% -55℃~+155℃ 82Ω 0603 Chip Resistor - Surface Mount ROHS | R18, R19 | 0603WAF820JT5E | C23255 | RES_0603 | 2 | RES_82R_0603_0.1W_1%
RES_22R_0805_0.125W_1% | 125mW Thick Film Resistors 150V ±100ppm/℃ ±1% -55℃~+155℃ 22Ω 0805 Chip Resistor - Surface Mount ROHS | R20, R32 | 0805W8F220JT5E | C17561 | RES_0805 | 2 | RES_22R_0805_0.125W_1%
RES_1K8_0805_0.125W_1% | 125mW Thick Film Resistors 150V ±100ppm/℃ ±1% -55℃~+155℃ 1.8kΩ 0805 Chip Resistor - Surface Mount ROHS | R21 | 0805W8F1801T5E | C17398 | RES_0805 | 1 | RES_1K8_0805_0.125W_1%
RES_5K6_0805_0.125W_1% | 125mW Thick Film Resistors 150V ±100ppm/℃ ±1% -55℃~+155℃ 5.6kΩ 0805 Chip Resistor - Surface Mount ROHS | R22 | 0805W8F5601T5E | C4382 | RES_0805 | 1 | RES_5K6_0805_0.125W_1%
RES_11K8_0805_0.125W_1% | 125mW Thick Film Resistors 150V ±100ppm/℃ ±1% -55℃~+155℃ 11.8kΩ 0805 Chip Resistor - Surface Mount ROHS | R23 | 0805W8F1182T5E | C17420 | RES_0805 | 1 | RES_11K8_0805_0.125W_1%
RES_0R_0805_0.125W_1% | 125mW Thick Film Resistors 150V ±800ppm/℃ ±1% -55℃~+155℃ 0Ω 0805 Chip Resistor - Surface Mount ROHS | R24, R26, R29, R31 | 0805W8F0000T5E | C17477 | RES_0805 | 4 | RES_0R_0805_0.125W_1%
RES_560K_2512_1W_1% | 1W ±100ppm/℃ ±5% 560kΩ 2512 Chip Resistor - Surface Mount ROHS | R25 | RC-12K564JT | C454037 | RES_2512 | 1 | RES_560K_2512_1W_1%
RES_1K37_0805_0.125W_1% | 125mW Thick Film Resistors 150V ±100ppm/℃ ±1% -55℃~+155℃ 1.37kΩ 0805 Chip Resistor - Surface Mount ROHS | R27 | CR0805F1K37P05Z | C245260 | RES_0805 | 1 | RES_1K37_0805_0.125W_1%
RES_180K_0805_0.125W_1% | 125mW Thick Film Resistors 150V ±100ppm/℃ ±1% -55℃~+155℃ 180kΩ 0805 Chip Resistor - Surface Mount ROHS | R28 | 0805W8F1803T5E | C17501 | RES_0805 | 1 | RES_180K_0805_0.125W_1%
RES_5K_SMD-POT_0.15mW_25% | ±25% ±250ppm/℃ 5kΩ SMD Variable Resistors/Potentiometers ROHS | R30 | VG039NCHXTB502 | C128557 | RES_SMD_POT_3PINS | 1 | RES_5K_SMD-POT_0.15mW_25%
RES_22K_0805_0.125W_1% | 125mW Thick Film Resistors 150V ±100ppm/℃ ±1% -55℃~+155℃ 22kΩ 0805 Chip Resistor - Surface Mount ROHS | R33, R38 | 0805W8F2202T5E | C17560 | RES_0805 | 2 | RES_22K_0805_0.125W_1%
RES_1K_0805_0.125W_1% | 125mW Thick Film Resistors 150V ±100ppm/℃ ±1% -55℃~+155℃ 1kΩ 0805 Chip Resistor - Surface Mount ROHS | R34 | 0805W8F1001T5E | C17513 | RES_0805 | 1 | RES_1K_0805_0.125W_1%
RES_100K_0805_0.125W_1% | 125mW Thick Film Resistors 150V ±100ppm/℃ ±1% -55℃~+155℃ 100kΩ 0805 Chip Resistor - Surface Mount ROHS | R35 | 0805W8F1003T5E | C149504 | RES_0805 | 1 | RES_100K_0805_0.125W_1%
RES_3K_0805_0.125W_1% | 125mW Thick Film Resistors 150V ±100ppm/℃ ±1% -55℃~+155℃ 3kΩ 0805 Chip Resistor - Surface Mount ROHS | R37 | 0805W8F3001T5E | C17661 | RES_0805 | 1 | RES_3K_0805_0.125W_1%
TESTPOINT_BD2.5mm_MHD1mm | Black PC Test Point, Miniature Phosphor Bronze Silver Plating Through Hole Mounting Type | TP_12V-AUX, TP_COMP, TP_COMP_ACIN, TP_GND, TP_ISOGND, TP_MODB, TP_S_ISOGND, TP_SGND, TP_SS, TP_Verr, TP_Vfb_Div, TP_Vout, TP_VREC | 5001 | ? | Test_Point_BD2.5mm_MHD_1mm | 16 | TESTPOINT_BD2.5mm_MHD1mm
Transformer_ETD34_SPLIT | Flyback converter transformer ETD34, 2 output winding, 1 input winding. | TRANS1 |  |  | ETD34_Horizontal_EXTRAPADS | 1 | Transformer_ETD34_SPLIT
DiodeBrige_600V_4A_TH-4-SIP-5.3mm | Full Wave Diode Bridge, 600V, 4A. | U1 | GBU406 | ? | 4_SIP | 1 | DiodeBrige_600V_4A_TH-4-SIP-5.3mm
OPTOCOUPLER_SFH615A-4XSMT/R | Optocoupler Dc-in 1-CH Transistor Dc-out 4-PIN PDIP SMD T/r | U2 |  |  | 4-SMD | 1 | OPTOCOUPLER_SFH615A-4XSMT/R
TL431AQDBZR | 2.495V~36V -40℃~+125℃@(TA) 700uA 100mA Adjustable SOT-23(SOT-23-3) Voltage References ROHS | U3 | TL431AQDBZR | C105255 | SOT-23 | 1 | SHUNTREG_TL431AQDBZR
UC3842AD8TR | SOIC-8_150mil AC-DC Controllers & Regulators ROHS | U4 | UC3842AD8TR | C182337 | SOIC-8 | 1 | PWMDRIVER_UC3842AD8TR

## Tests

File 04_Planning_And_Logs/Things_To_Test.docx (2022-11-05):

- Resistance of the NTC at Pmin. I need to potentially add a current meter test point on the PCB in order to measure the steady state current into the rectifier. Also need to add test points for the voltage across the NTC.
- Test the open-loop response of the converter if it matches the predicted. Possibly need to add some BNC on the PCB to interface with the spectrum analyser.
- Test the Inductor temperature at max load if it matches the simulation on maxwell.
- Individually test the saturation current of the inductor to see if it matches the design.
- Test if grounding the heatsink helps in reducing the EMI measurement using the “sniffing tool”.

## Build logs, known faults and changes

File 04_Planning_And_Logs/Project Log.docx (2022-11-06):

Picking components using simulation results:

A lazy way to do the component selection would be to use the simulation results and just add some safety margin. For example, if the simulation says the RMS of the output capacitor is 10A, then just pick a capacitor rated for 15A.

Adding a safety margin is needed because it is hard to determine the exact losses in the system. Even if I assume a certain efficiency, it is difficult to obtain the results without going through an intense mathematical derivation or reading reference books to find out the analytical solutions. It is much easier to just simulate and add some safety margin.

Controlling the dead time in the DCM

I’ve observed that the % inductance from the critical conduction mode seems to be roughly linearly controlling the deadtime. For example, the deadtime will be 0.8Ts if the primary inductance is 80% of the critical conduction mode inductance.

Current concerns:

1.)The instantaneous power goes up to 2.4kW I am not sure if this can be safely provided by the house’s wiring. It seems that this could even get higher as input voltage increases even more, because currently I am simulating with minimum input DC voltage.

Update: This can be mitigated by limiting the maximum current at the primary coil. Can easily be implemented using peak current mode control IC.

2.) I should simulate with the rectifier next and start thinking about the input capacitors.

Update(14 May 21): Input capacitor can be determined by the hold-up time considerations.

3.) The current limit is getting triggered first before the voltage limit. This needs to be looked at.

Issue: Picking the primary inductance to keep flyback at DCM

Picked 220uH for the primary inductance for now. The simulation model simulates with minimum Vin of 260VDC. The turns ratio is also set to 7 based on the output voltage of 24V and a maximum MOSFET voltage of 700V with 80% derating.

Both the max load and 10x of the max load regulates at 24V and the model is stable. However, at higher load, the model takes longer to settle at 24V.

Right now, the main concern that the secondary peak currents are too high (about 35A) when the current limit is set to 5A. However, it seems that the current limit can be set to 4A and the model will still regulate at 24V. In either case, I need to determine if such high currents are practical and can be built.

Update on current limit (May 5th 21): High currents up to 35A is possible if the trace widths are made wider, longer and thicker. Also for the diode on the secondary, the diodes can usually handle high current, but are need to be double check in the datasheet.

Another observation is that the peak current limit gives the system some output voltage overshoots as high as 35V @ 10x max load. This seems to be affected by the output capacitance and the peak current limit. A lower output capacitance gives lower overshoots.

With the current simulation model, the efficiency is about 88% @ maximum load. And the maximum primary current goes up to 3.92A. And the max input power go as high as 1kW @ maximum load.

With 10x of max load, the max input power goes up to 1.3kW.

Issue: Picking the bulk input capacitor

So far there seems to be some sort of rule of thumb like 2uF/W to estimate the capacitance needed for the input capacitor.

Update (May 5th 21): This rule of thumb depends on the voltage across the capacitor. Usually, this is so that the hold up time considerations are met.

The input capacitance cannot be made too big otherwise the RMS currents through it will increase.

The tolerance + end of life of a capacitor should also be considered to select the value of the input capacitor. For example, capacitance tolerance of 20% and end of life capacitance decrease of 20% this means that the capacitance should be at least 156.25% higher than the initial design. This is done so to make sure the designed input voltage drop don’t go too low and increase the duty cycle which could potentially saturate the inductors.

5/11/22 – 2:40PM

Change from DCM to CCM flyback

I decided to implement a CCM flyback instead of DCM. This is because I wanted to use a smaller core for the coupled inductor. With DCM, the core needed to be quite big to prevent saturation due the high peak current inherent with DCM. With CCM, the primary side inductor current isn’t as high thus, allowing me to use smaller core.

6/11/22 – 4:54PM

Verified the inductance of the coupled inductor using MAXWELL

I used MAXWELL to verify the inductance. The simulation outputs the “AL”, so given this information and knowing the turns I initially designed for I was able to calculate the inductance on the primary of the coupled inductor. The simulation output was 277.65nH/N^2 so this gives a total inductance of 966uH, which is higher than what is designed for which is 900uH. However, is alright since CCM operation is still ensured.

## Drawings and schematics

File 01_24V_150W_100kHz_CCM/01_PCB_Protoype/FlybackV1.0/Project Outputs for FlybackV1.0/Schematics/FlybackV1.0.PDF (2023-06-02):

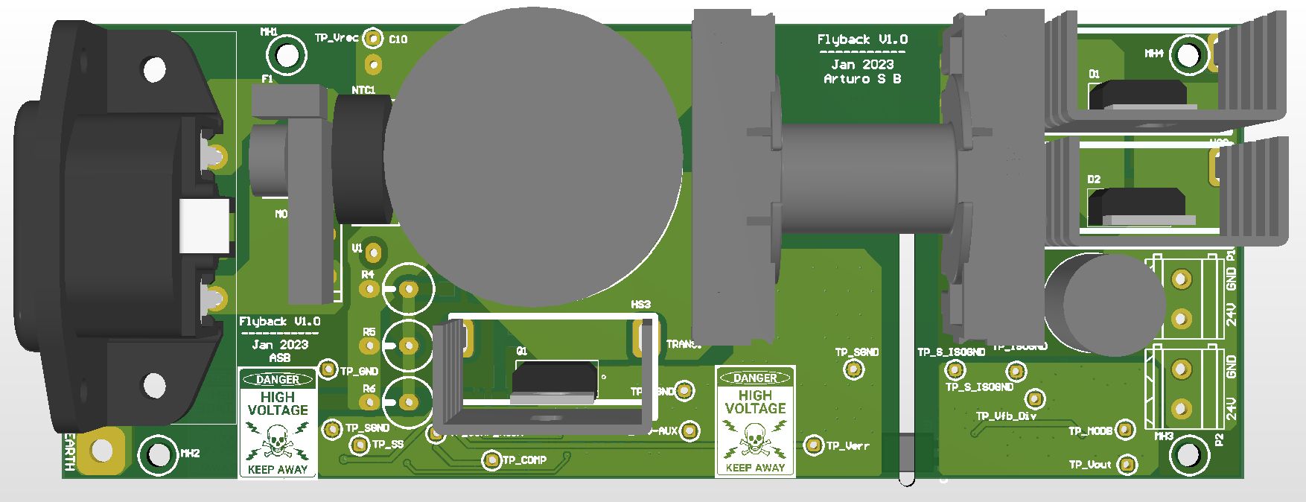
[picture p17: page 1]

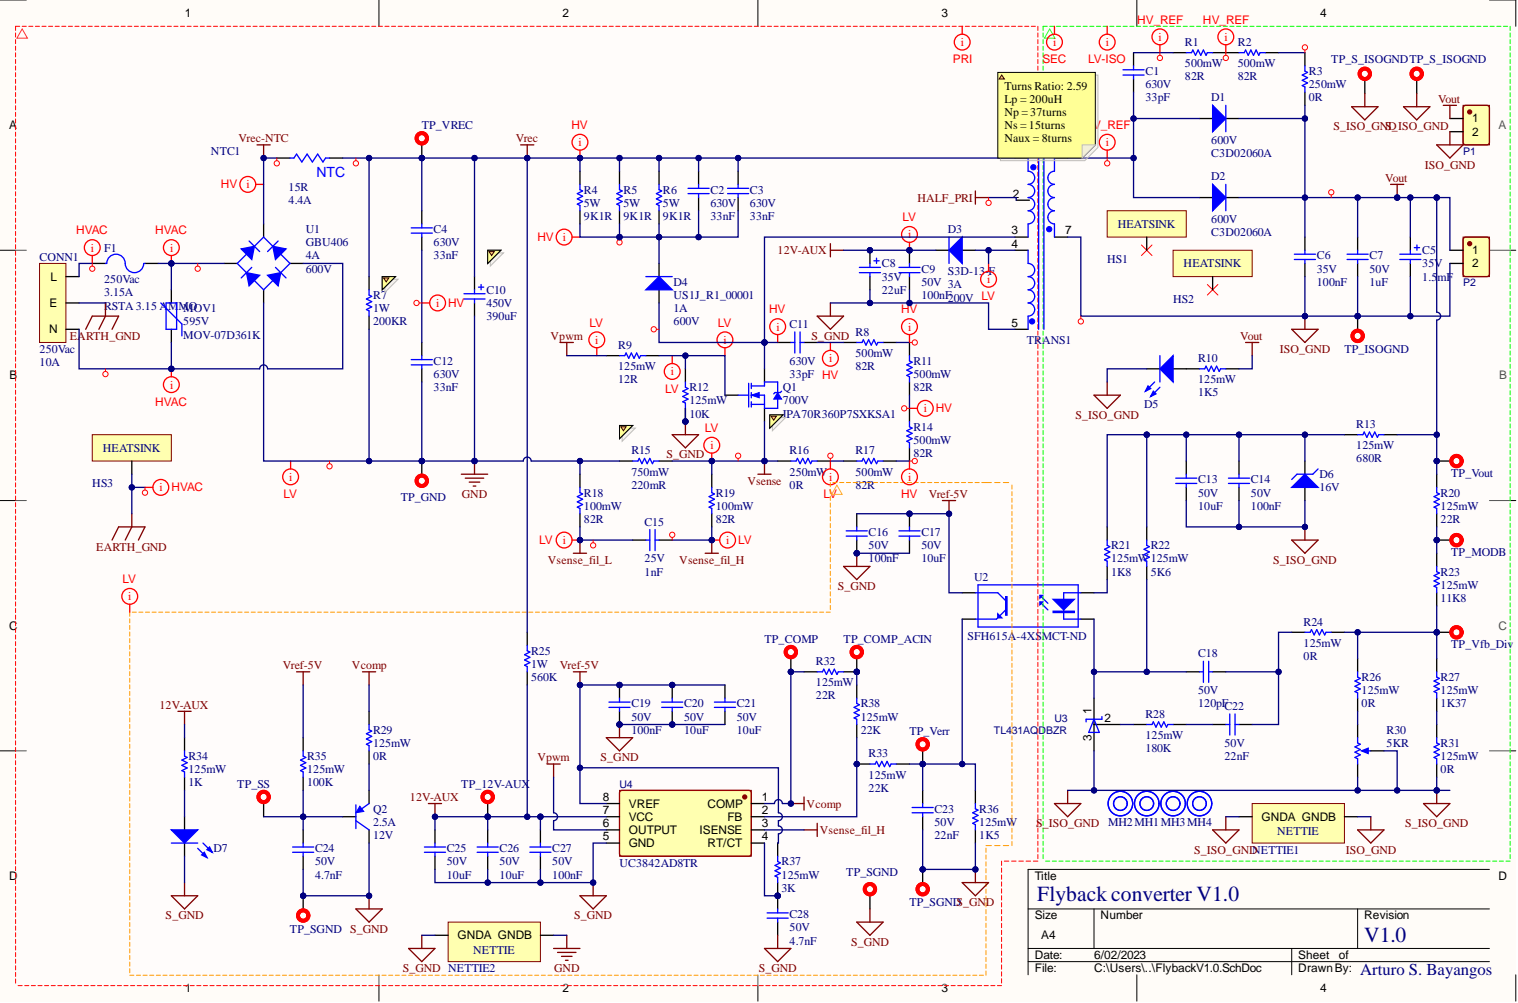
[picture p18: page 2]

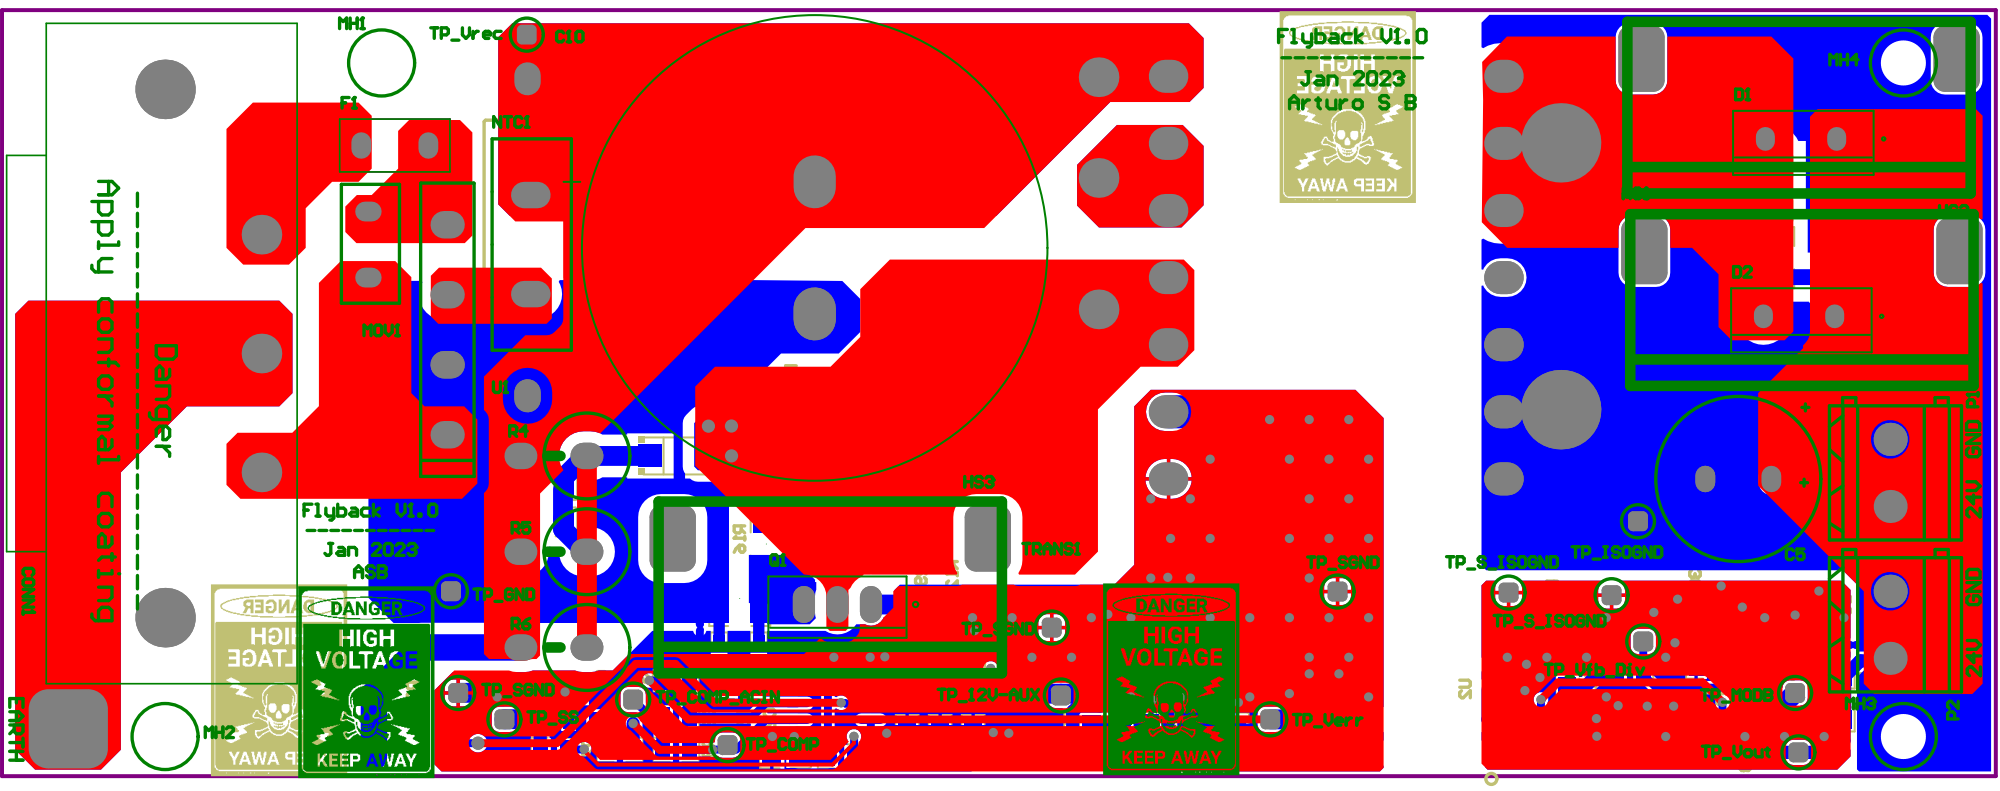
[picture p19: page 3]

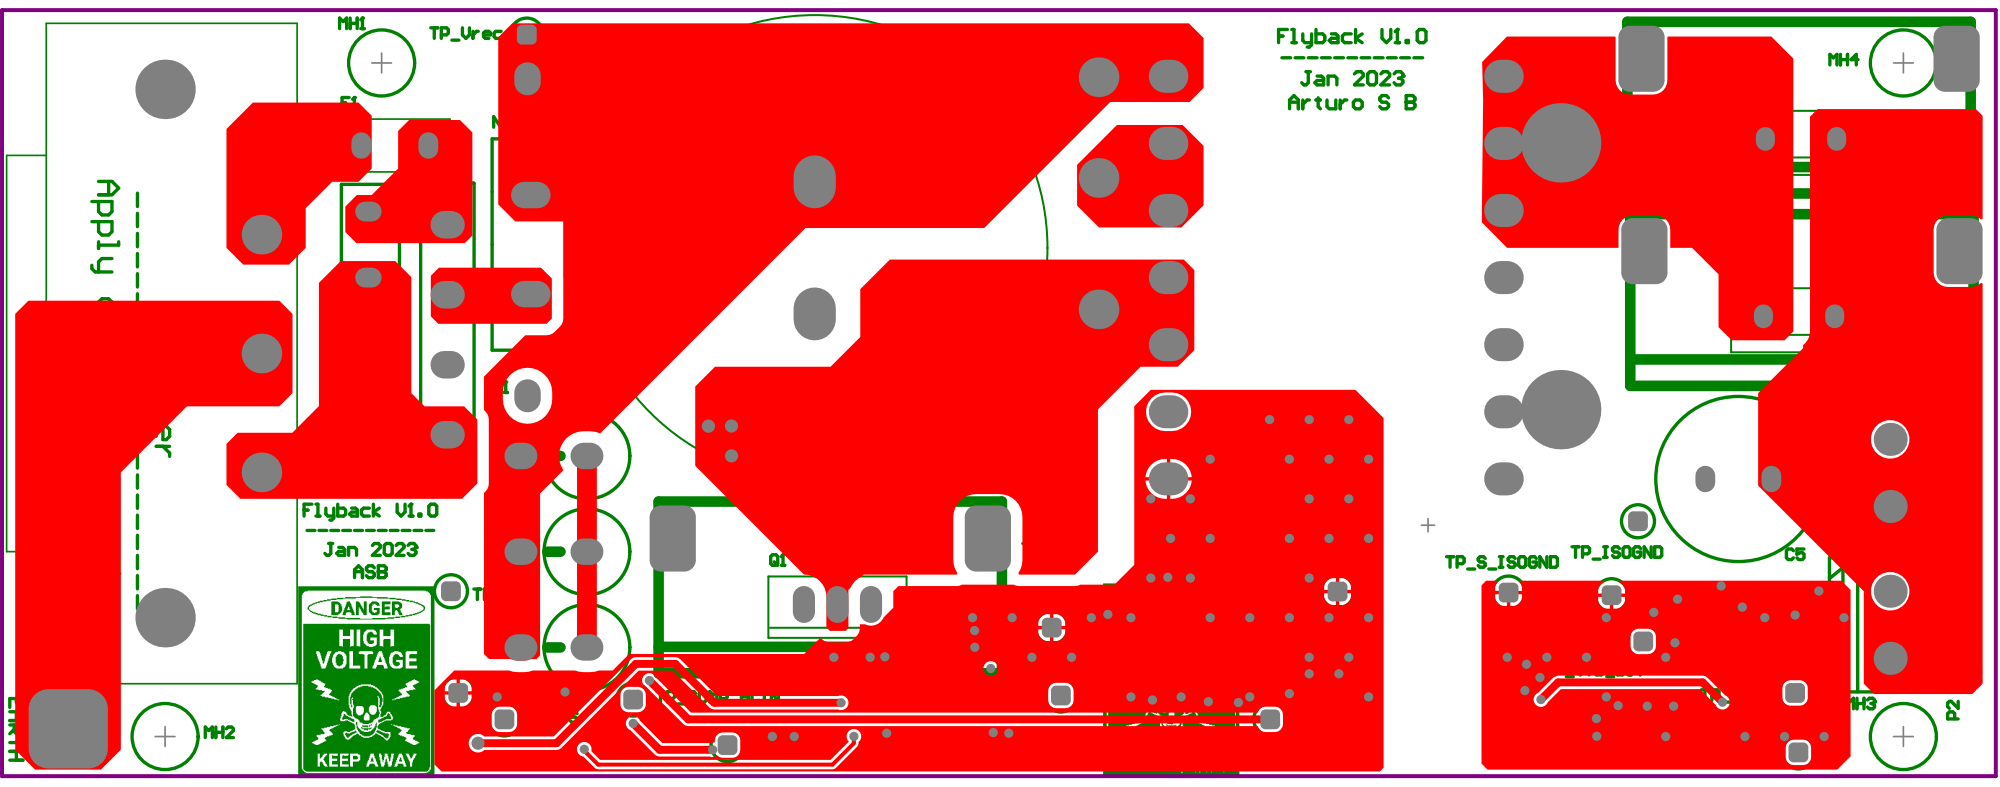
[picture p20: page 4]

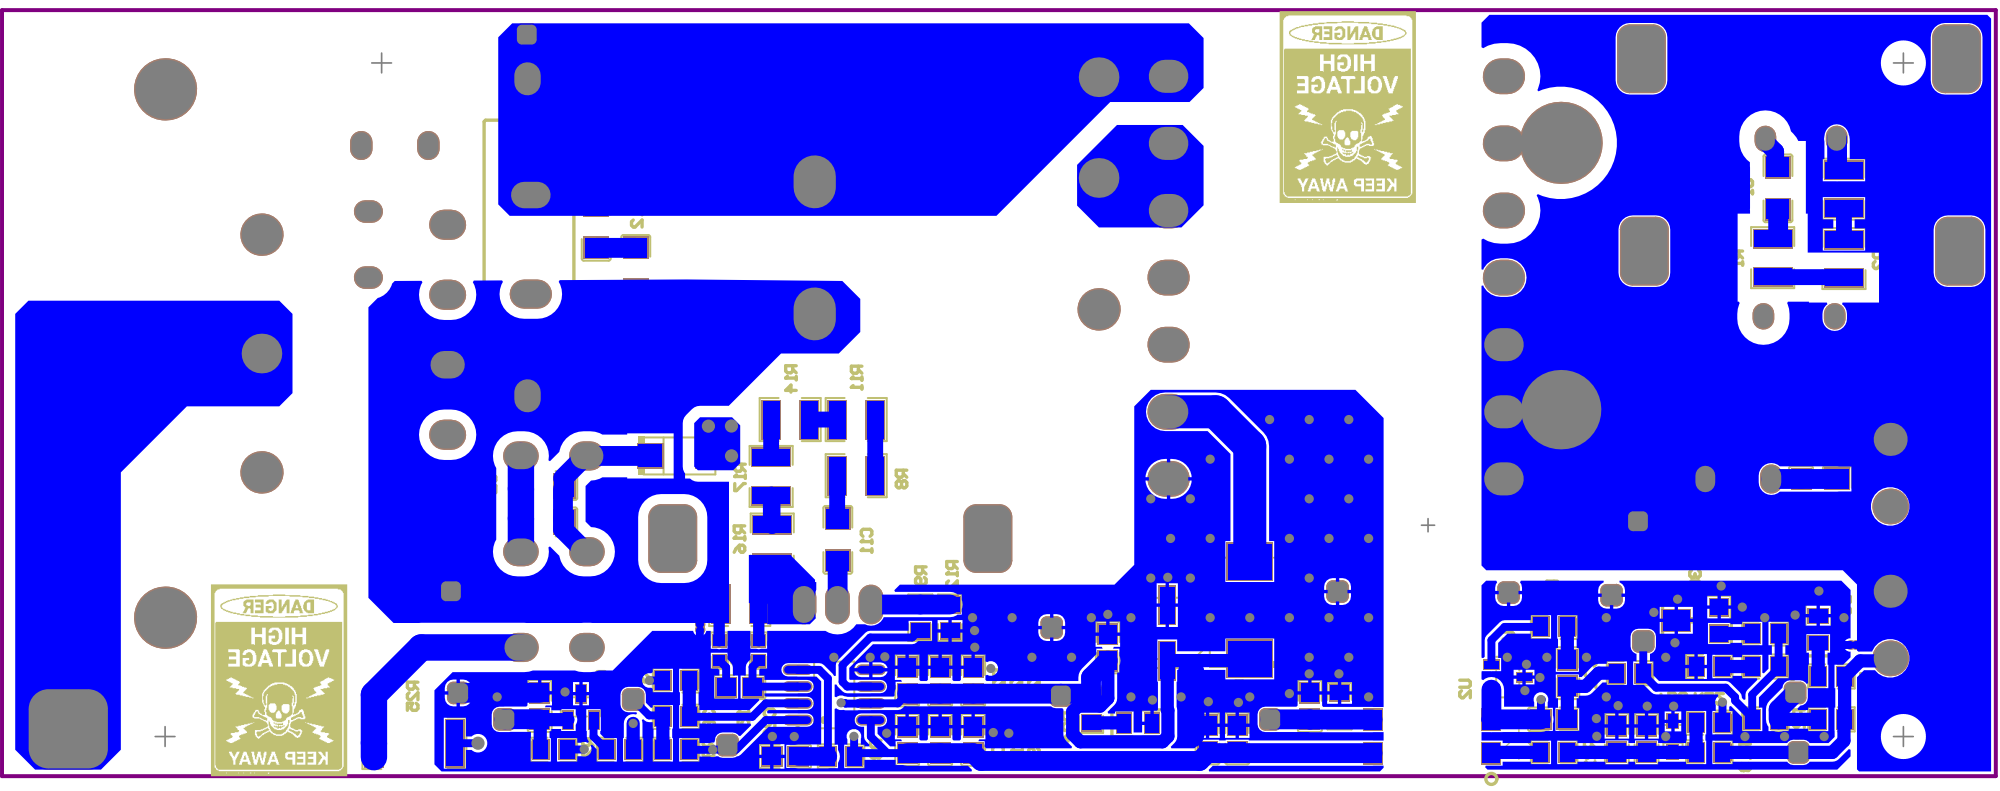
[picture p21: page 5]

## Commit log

2022-04-02 Upload Initial specification for the 150W,12V DCM flyback
2022-07-02 Squashed commit of the following:
    commit 6649967d16159932f6a7cdcc41de064de72a33dd
    Author: ambibayangos <48893064+ambibayangos@users.noreply.github.com>
    Date: Sat Jul 2 17:37:23 2022 +1200
    Investigated peak input power
    Investigated the input power for the 150W DCM flyback converter for 12V and 24V output voltage. Have found that the peak input current may at the primary is too high and is quite dangerous for the house use since houses can only supply about 3kW whereas the DCM input has peak power of 3.8kW. Using CCM may be more feasible.
    commit 75ba64463e7762bfc5b91274f25f61187b61ee99
    Merge: 24e012e 8849cfb
    Author: ambibayangos <48893064+ambibayangos@users.noreply.github.com>
    Da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
    [12V_150W_Parameter calulator.xlsx, 24V_150W_Parameter calulator.xlsx, Parameter_Calculator.xlsx]
2022-11-05 Re organise the file structure
    [12V_150W_Parameter calulator.xlsx, 2022-08-14T044307.xlsx, 24V_150W_100kHz_CCM_Parameter_Calculator.xlsx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]
2022-11-06 Verify primary inductance value using MAXWELL
    The simulated ETD44 with 1mm airgap with 59 turns gave an inductance value of 960uH. This is higher than what is designed for (900uH) but is alright since this inductance value would still ensure CCM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
    [24V_150W_100kHz_CCM_Parameter_Calculator.xlsx]
2022-11-16 Verified the saturation current for 2mm airgap - ETD34 N87
    The simulation result for Bsat of 0.3T roughly matches what the manufacturer says the Isat is. However, the inductance value, does not seem to match the "AL" given by the manifacturer vs the simulate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
    [24V_150W_100kHz_CCM_Parameter_Calculator.xlsx, Arturo_PCB.PcbLib, Arturo_PCB.SchLib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]
2022-11-20 Created MAXWELL model for the ETD44 for verifying coreloss and Bsat
    Was able to verify the Bsat of the ETD44 with 1.5mm airgap. Currently, the B is about 300mT at 4A (3.5A at fully power). Also made a transient model on maxwell to evaluate the coreloss and eventually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
    [current_waveforms_fourier.csv]
2022-11-27 Maxwell + Icepak simulation result for ETD44 (max temp rise is 25degC)
    for ETD 44 1.5mm airgap, @ Vin = 293V , Fs = 100kHz, RL = 3.84 , D = 0.18. The core loss is about 0.2W , the copper loss is about 1W. The maximum temp rise is 25degC and it occurs around the copper w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
2022-11-27 Add pyhton scripts that gives the fourier expansion of the pri and sec current waveforms
    This method didnt go to well. the maxwell crashes and is too slow when it worked because there was a lot of sinusoid terms required to approximate the current waveforms. Anyway, I found a better solution.
    [PWM.csv, current_waveforms_fourier.csv]
2022-11-27 Renamed the working Maxwell + Simplorer + Icepak project
    Use this to simulate ETD44 at any airgap to determine the max temperature rise and the losses on the core and windings.
2022-11-27 Added research document ( Why choose certain core geometries)
    Basically, looks like I picked the correct core geometry (ETD - which is lucky). Basically, this core shape is good for high power applications due to fact that it offers lower path length and have a wider opening to cool the coils more efficiently.
2022-11-30 Pick input caps based by balancing the input RMS, inductor peak current, and switch RMS.
    Looks like the input capacitor value should be around 350 - 450uF (This interestly follows the 3uF/W rule) exept my model does not fully factor in the efficiency.
    [24V_150W_100kHz_CCM_Parameter_Calculator.xlsx, Flyback_CCM_150_24V_100KHz_V1.0.PrjPcb, Flyback_CCM_150_24V_100KHz_V1.0.SchDoc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]
2022-12-14 Finished schematic of "Power section"
    Picked, Fuse, NTC and MOV. Designed Bleed resistor, RCD clamp and RC snubber, designed new transformer ETD34. Pick input and output caps. Ready to do the controller section next!
    [2022-12-10T040316.csv, 2022-12-14T045043.csv, 24V_150W_100kHz_CCM_Parameter_Calculator.xlsx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]
2023-01-06 Completed schematic and PCB layout - but there is a design problem!
    Completed schematic and PCB layout - but there is a design problem. The design problem is that the reflected voltage on the secondary is too high above atleast 138V. This is due to low turns ratio. Next design iteration will need the reflected voltage kept around 30V.
    [2022-12-26T060951.csv, 2023-01-05T004533.csv, Arturo_PCB.PcbLib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]
2023-01-06 Modified the high voltage marking location, also included part number on the BOM
    Modified the high voltage marking location, also included part number on the BOM
    [Bill of Materials-FlybackV1.0.xlsx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]
2023-02-25 Made the silk screen text on one direction for easy readability. Also upload a document that details transformer construction
    [Arturo_PCB.PcbLib, Arturo_PCB.SchLib, FlybackV1.0.PcbDoc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]
2023-06-02 Restructure files
    [12V_150W_Parameter calulator.xlsx, 2022-08-14T044307.xlsx, 2022-12-10T040316.csv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]
2023-06-02 Add schematic and PCB prints on readme.md
2023-09-24 Copy V1.0 Schmatics & PCB before re-doing the schematics
    I am redoing the schematics because the current schematic
    looks is too messy because all the power and control section
    are integrated into one sheet.
    Another reason I am redoing schematic is because the current
    schematics uses A1 or something very large which is hard to print.
    I want to use A3 which is more readily available.
    [Arturo_PCB.PcbLib, Arturo_PCB.SchLib, FlybackV1.0.PcbDoc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]
2023-09-26 Upload screenshot of the temperature eval for ETD34
